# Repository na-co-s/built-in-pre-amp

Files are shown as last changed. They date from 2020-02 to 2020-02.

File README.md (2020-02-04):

# na-co's built-in pre amp
Pre amp for embedding in guitar. Replace the output jack with TRS and supply +12V to the ring for use.

https://yokuhizumu.art.blog/

## Connectors
### J1, J2 and U2 (Top view)
- J1: Connect to pickup selector
- J2: Connect to LED (Resistor is required)
- U2: Connect to dual triode vacuum tube

|||
|---|---|
|(J1) GND|(J1) IN|
|(J2) GND|(J2) +12V|
|(U2) GND|(U2) +12V|
|(U2) GND|(U2) K1|
|(U2) G2|(U2) G1|
|(U2) P2|(U2) P1|

### RV1, RV2, RV3, J3 and J4 (Top view)
- J3: Connect to output TRS jack (Sleeve and Tip)
- J4: Connect to output TRS jack (Ring)

|||
|---|---|
|(RV2) VOLUME IN|(J4) +12V|
|(RV2) VOLUME OUT|(J3) OUT|
|(RV2) GND|(J3) GND|
|(RV1) GAIN IN|(RV3) TONE IN|
|(RV1) GAIN OUT|(RV3) TONE OUT|
|(RV1) GND|(RV3) N.C.|

### J5
- J5: Connect to external voltage source for plate (Option)

## Jumpers
### JP1 Relay
If a short pin is connected to pins 1-2, the relay will always be energized as long as +12V is supplied to J4.  
If a footswitch is connected to pins 1-2, the relay will be energized only when the footswitch is on.  

### JP2 Plate Voltage
If a short pin is connected to pins 1-2, +12V supplied to J4 will be supplied to the plate.  
If a short pin is connected to pins 2-3 and an external voltage is supplied to J5, that voltage will be supplied to the plate.  

## BOM
|Ref|Val|
|---|---|
|K1|EA2-12NU|
|U1|LM386N-4|
|U2|12AU7|
|R1|1K|
|R2|100K|
|R3|470K|
|R4|47K|
|C1|223|
|C2|223|
|C3|223|
|C4|223|
|RV1|A250K|
|RV2|A250K|
|RV3|A250K|

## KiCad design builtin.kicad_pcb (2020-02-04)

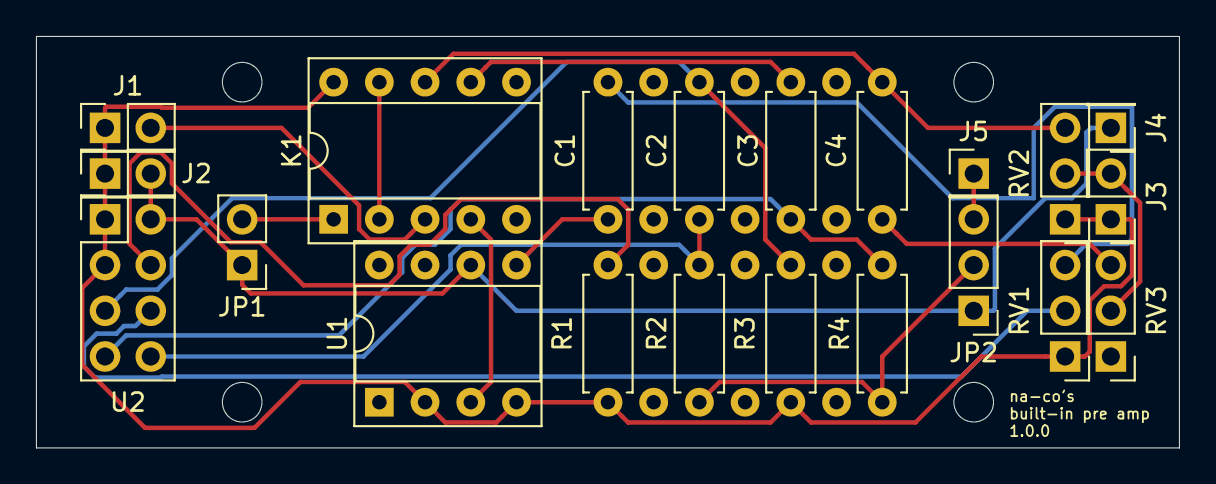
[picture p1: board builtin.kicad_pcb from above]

Board: 2 copper layers, 63.5 x 22.9 mm, 21 parts (0 on the bottom side), 19 nets.

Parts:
C1, C2, C3, C4: 223; R_Axial_DIN0207_L6.3mm_D2.5mm_P7.62mm_Horizontal
J1: INPUT; PinHeader_2x01_P2.54mm_Vertical
J2: LED; PinHeader_2x01_P2.54mm_Vertical
J3: OUTPUT; PinHeader_1x02_P2.54mm_Vertical
J4: +12V; PinHeader_1x01_P2.54mm_Vertical
J5: PLATE VOLTAGE; PinHeader_1x01_P2.54mm_Vertical
JP1: Foot Switch; PinHeader_1x02_P2.54mm_Vertical
JP2: Plate Voltage; PinHeader_1x03_P2.54mm_Vertical
K1: Bypass; DIP-10_W7.62mm_Socket
R1: 1K; R_Axial_DIN0207_L6.3mm_D2.5mm_P7.62mm_Horizontal
R2: 100K; R_Axial_DIN0207_L6.3mm_D2.5mm_P7.62mm_Horizontal
R3: 470K; R_Axial_DIN0207_L6.3mm_D2.5mm_P7.62mm_Horizontal
R4: 47K; R_Axial_DIN0207_L6.3mm_D2.5mm_P7.62mm_Horizontal
RV1: GAIN; PinHeader_1x03_P2.54mm_Vertical
RV2: VOLUME; PinHeader_1x03_P2.54mm_Vertical
RV3: TONE; PinHeader_1x03_P2.54mm_Vertical
U1: LM386; DIP-8_W7.62mm_Socket
U2: ECC83; PinHeader_2x04_P2.54mm_Vertical

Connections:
+12V: J2.2, J4.1, JP1.1, JP2.1, U1.6, U2.5
GND: J1.1, J2.1, J3.1, K1.10, R1.2, R3.2, RV1.1, RV2.1, U1.2, U1.4, U2.3, U2.4
unnamed: C1.1, U1.5
unnamed: C1.2, RV1.3
unnamed: C2.1, R2.2, U2.6
unnamed: C2.2, R3.1, U2.2
unnamed: C3.1, R4.2, U2.1
unnamed: C3.2, K1.7
unnamed: C4.1, K1.8, RV2.3
unnamed: C4.2, RV3.3
unnamed: J1.2, K1.3
unnamed: J3.2, RV2.2, RV3.2
unnamed: J5.1, JP2.3
unnamed: JP1.2, K1.1
unnamed: JP2.2, R2.1, R4.1
unnamed: K1.2, K1.9
unnamed: K1.4, U1.3
unnamed: R1.1, U2.8
unnamed: RV1.2, U2.7
